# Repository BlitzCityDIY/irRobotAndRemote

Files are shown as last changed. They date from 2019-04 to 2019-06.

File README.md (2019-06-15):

This is for a rover robot built with the Adafruit Crickit board. 

It's controlled with an IR remote using an Adafruit Trinket M0, Adafruit Seesaw and custom PCB.

Coded with CircuitPython.

Project Videos:

https://youtu.be/yoQC8QCEBIY

https://youtu.be/6JI83SIRhTM

https://youtu.be/Heaa0BWK_Mk

https://youtu.be/sYn7sI7BDCw

Fusion 360 Public Links

Remote Main Body: https://a360.co/2XNJTZd

LED Cat Faceplate: https://a360.co/2WIM9Eo

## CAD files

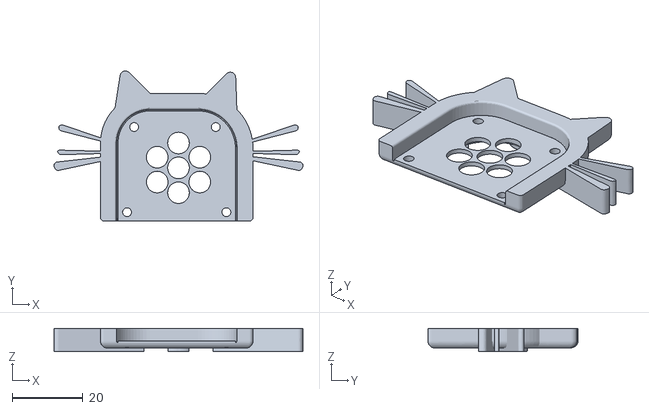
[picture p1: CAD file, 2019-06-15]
catFaceLedCover_v3.stl
70.2 x 42.3 x 6.57

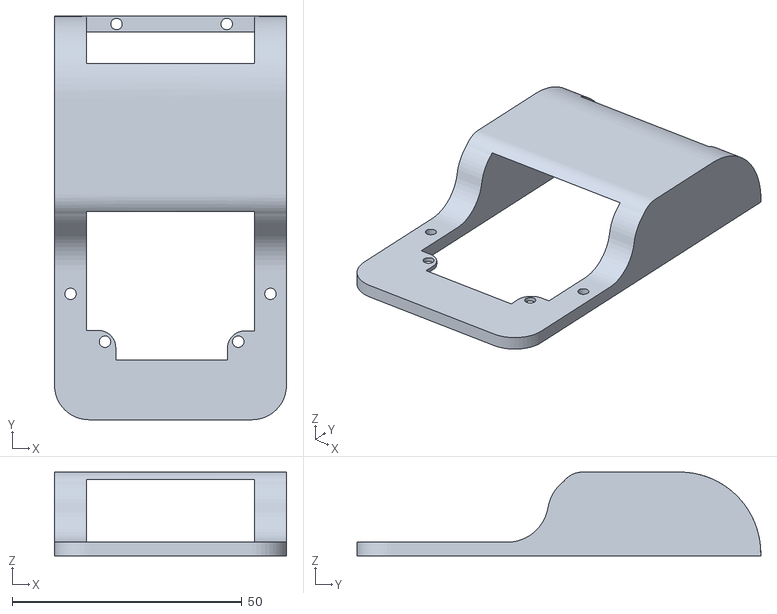
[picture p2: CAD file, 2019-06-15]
irRemoteBodyTop_v4.stl
50.5 x 87.8 x 18.3

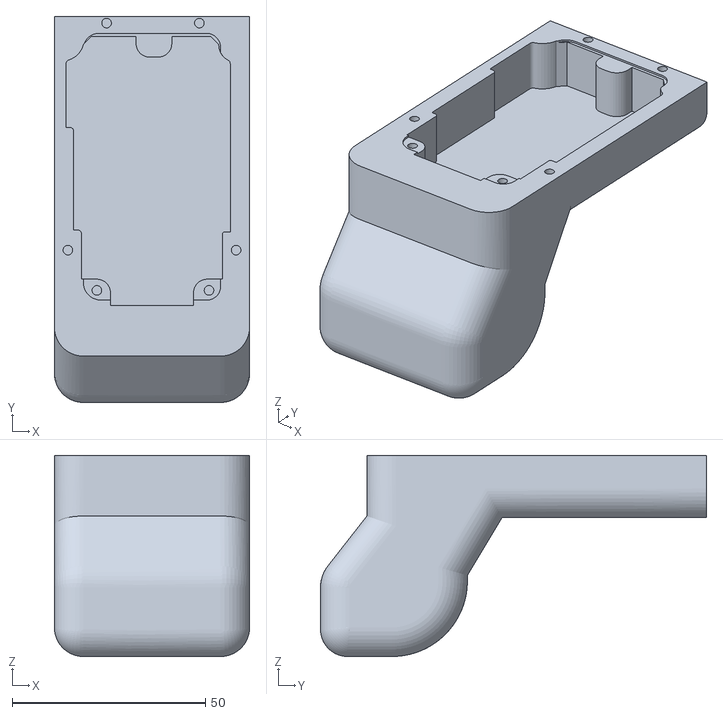
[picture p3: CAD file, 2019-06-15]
irRemoteBodyHandle_v4.stl
50.5 x 99.8 x 52.0

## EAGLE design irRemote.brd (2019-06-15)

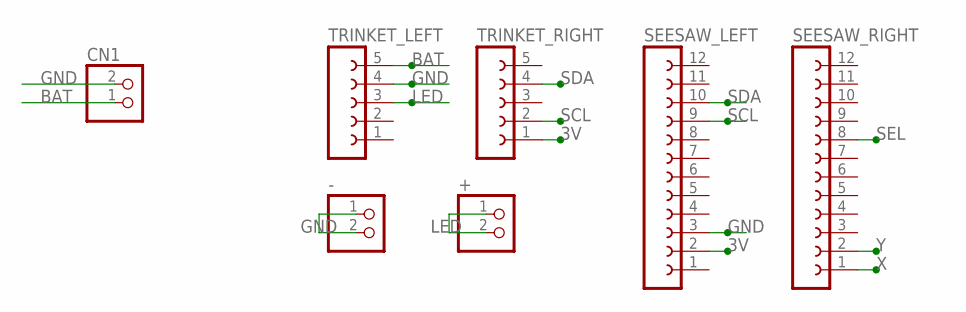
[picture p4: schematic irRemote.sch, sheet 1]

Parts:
+: PINHD-1X2; 1X02
-: PINHD-1X2; 1X02
CN1: JST_2PIN-SMT-RA; JST-PH-2-SMT-RA
SEESAW_LEFT: FE12-1; FE12
SEESAW_RIGHT: FE12-1; FE12
TRINKET_LEFT: FE05-1
TRINKET_RIGHT: FE05-1

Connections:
3V: SEESAW_LEFT.2, TRINKET_RIGHT.1; also elsewhere on the board
BAT: CN1.1 (2), TRINKET_LEFT.5
GND: -.1, -.2, CN1.2 (1), SEESAW_LEFT.3, TRINKET_LEFT.4; also elsewhere on the board
LED: +.1, +.2, TRINKET_LEFT.3
SCL: SEESAW_LEFT.9, TRINKET_RIGHT.2
SDA: SEESAW_LEFT.10, TRINKET_RIGHT.4
SEL: SEESAW_RIGHT.8; also elsewhere on the board
X: SEESAW_RIGHT.1; also elsewhere on the board
Y: SEESAW_RIGHT.2; also elsewhere on the board

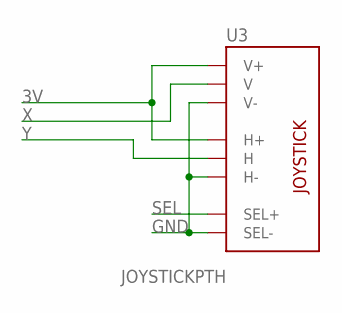
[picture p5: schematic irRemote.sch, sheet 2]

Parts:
U3: JOYSTICKPTH; JOYSTICK

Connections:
3V: U3.H1 (H+), U3.V1 (V+); also elsewhere on the board
GND: U3.B2A (SEL-), U3.H3 (H-), U3.V3 (V-); also elsewhere on the board
SEL: U3.B1A (SEL+); also elsewhere on the board
X: U3.V2 (V); also elsewhere on the board
Y: U3.H2 (H); also elsewhere on the board

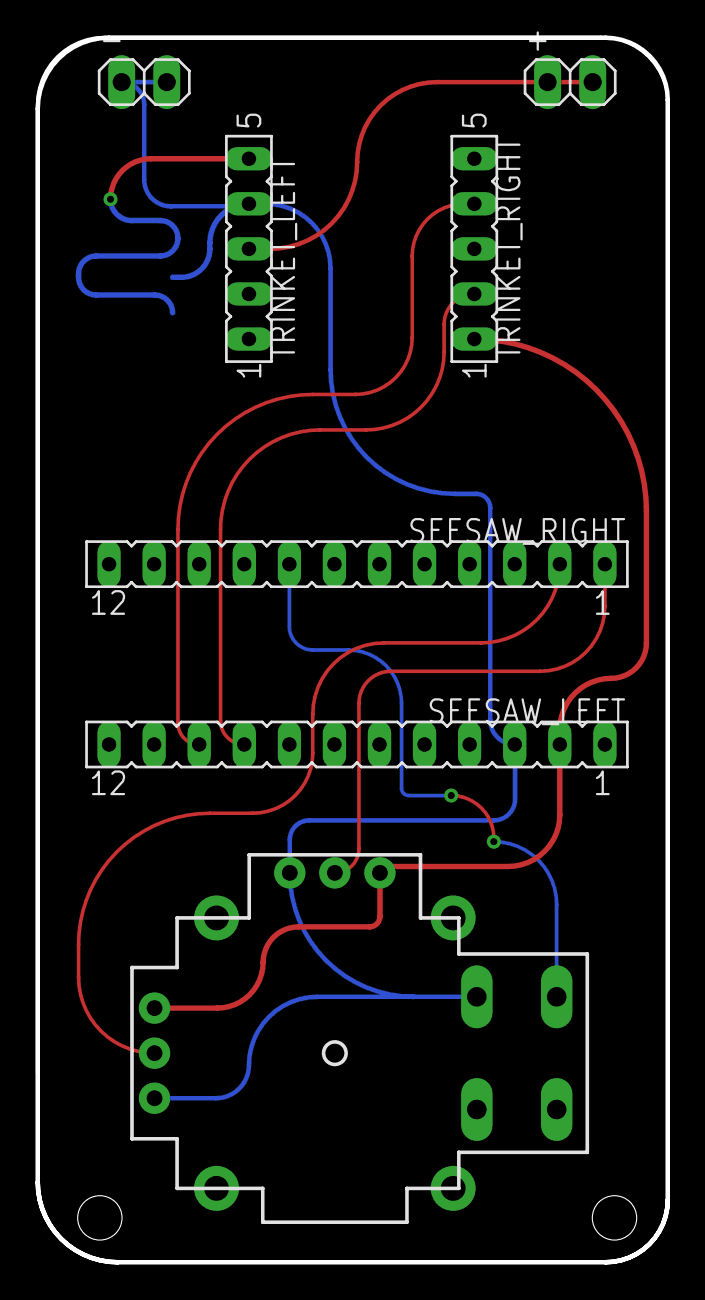
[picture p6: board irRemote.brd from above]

Board: 2 copper layers, 35.5 x 69.0 mm, 8 parts (1 on the bottom side), 9 nets.

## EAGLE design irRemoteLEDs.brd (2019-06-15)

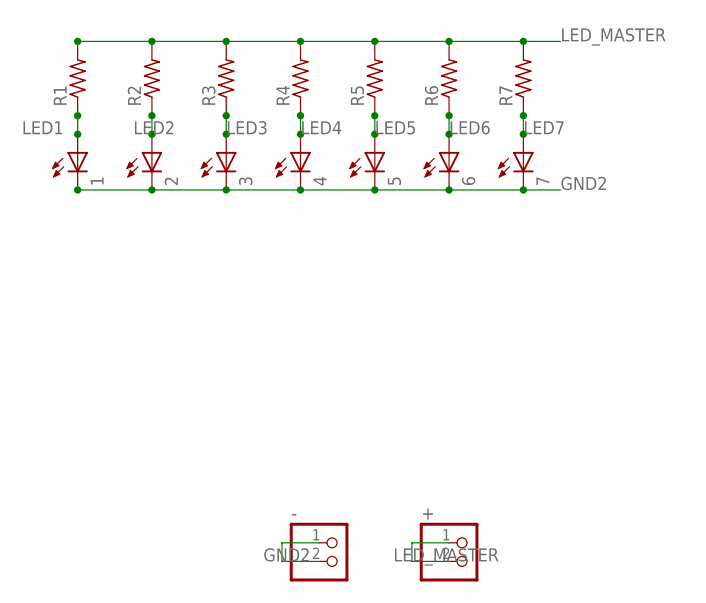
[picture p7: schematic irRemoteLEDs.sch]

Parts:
1, 2, 3, 4, 5, 6, 7: LED5MM
+: PINHD-1X2; 1X02
-: PINHD-1X2; 1X02
R1, R2, R3, R4, R5, R6, R7: R-US_M0805; M0805

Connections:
GND2: 1.K (C), 2.K (C), 3.K (C), 4.K (C), 5.K (C), 6.K (C), 7.K (C), -.1, -.2
LED1: 1.A, R1.1
LED2: 2.A, R2.1
LED3: 3.A, R3.1
LED4: 4.A, R4.1
LED5: 5.A, R5.1
LED6: 6.A, R6.1
LED7: 7.A, R7.1
LED_MASTER: +.1, +.2, R1.2, R2.2, R3.2, R4.2, R5.2, R6.2, R7.2

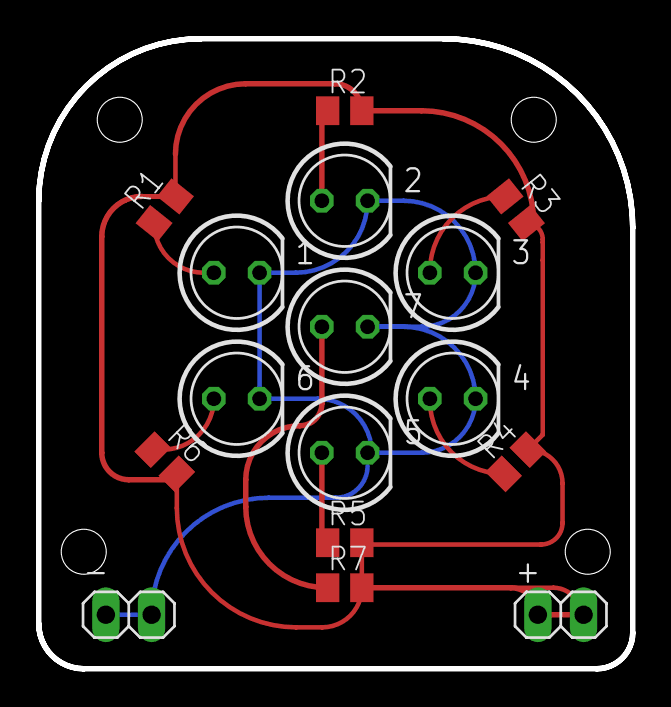
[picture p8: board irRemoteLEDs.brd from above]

Board: 2 copper layers, 33.0 x 35.0 mm, 16 parts (0 on the bottom side), 9 nets.

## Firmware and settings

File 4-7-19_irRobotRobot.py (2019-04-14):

import pulseio
import board
import adafruit_irremote
import time
from adafruit_crickit import crickit

motor_1 = crickit.dc_motor_1
motor_2 = crickit.dc_motor_2

# Create a 'pulseio' input, to listen to infrared signals on the IR receiver
pulsein = pulseio.PulseIn(board.IR_RX, maxlen=120, idle_state=True)
# Create a decoder that will take pulses and turn them into numbers
decoder = adafruit_irremote.GenericDecode()

while True:
    pulses = decoder.read_pulses(pulsein)
    try:
        # Attempt to convert received pulses into numbers
        received_code = decoder.decode_bits(pulses, debug=False)
    except adafruit_irremote.IRNECRepeatException:
        # We got an unusual short code, probably a 'repeat' signal
        # print("NEC repeat!")
        continue
    except adafruit_irremote.IRDecodeException as e:
        # Something got distorted or maybe its not an NEC-type remote?
        # print("Failed to decode: ", e.args)
        continue

    #  print("NEC Infrared code received: ", received_code)
    if received_code == [255, 2, 255, 0]:
        #  print("forward")
        motor_1.throttle = -0.5
        motor_2.throttle = -0.5 # half speed backward
        time.sleep(0.001)
    if received_code == [255, 2, 127, 128]:
        #  print("back")
        motor_1.throttle = 0.5
        motor_2.throttle = 0.5 # half speed backward
        time.sleep(0.001)
    if received_code == [255, 2, 100, 22]:
        #  print("left")
        motor_1.throttle = -0.5
        motor_2.throttle = 0.5 # half speed backward
        time.sleep(0.001)
    if received_code == [255, 2, 164, 0]:
        #  print("right")
        motor_1.throttle = 0.5
        motor_2.throttle = -0.5 # half speed backward
        time.sleep(0.001)
    if received_code == [255, 2, 191, 64]:
        #  print("stop")
        motor_1.throttle = 0
        motor_2.throttle = 0 # stop
        time.sleep(0.001)

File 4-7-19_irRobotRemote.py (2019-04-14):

import time
from board import SCL, SDA
import board
import adafruit_irremote
import pulseio
import busio
from adafruit_seesaw.seesaw import Seesaw

i2c_bus = busio.I2C(SCL, SDA)

pwm = pulseio.PWMOut(board.D4, frequency=38000, duty_cycle=2 ** 15)
pulseout = pulseio.PulseOut(pwm)
# Create an encoder that will take numbers and turn them into NEC IR pulses
encoder = adafruit_irremote.GenericTransmit(header=[9500, 4500], one=[550, 550],
                                            zero=[550, 1700], trail=0)
 
ss = Seesaw(i2c_bus)

ss.pin_mode(9, ss.INPUT_PULLUP)

last_x = 0
last_y = 0
 
while True:
    x = ss.analog_read(2)
    y = ss.analog_read(3)
    b = ss.digital_read(9)

    if not b:
            encoder.transmit(pulseout, [255, 2, 191, 64])
            time.sleep(.01)
    if (abs(x - last_x) > 3) or (abs(y - last_y) > 3):
        #  print(x, y)
        last_x = x
        last_y = y
        if x > 500 and y > 995:
            #  cpx.pixels.fill((50, 0, 0))
            encoder.transmit(pulseout, [255, 2, 255, 0])
            time.sleep(.01)
            #  forward
        if x < 10 and y > 500:
            #  cpx.pixels.fill((0, 50, 0))
            encoder.transmit(pulseout, [255, 2, 100, 22])
            time.sleep(.01)
            #  left
        if x > 995 and y > 500:
            #  cpx.pixels.fill((0, 0, 50))
            encoder.transmit(pulseout, [255, 2, 164, 0])
            time.sleep(.01)
            #  right
        if x > 500 and y < 10:
            #  cpx.pixels.fill((0, 0, 50))
            encoder.transmit(pulseout, [255, 2, 127, 128])
            time.sleep(.01)
            #  back

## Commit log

2019-04-14 IR Robot and IR Remote CircuitPython code files
2019-06-15 Eagle files for the IR remote PCBs
    Includes schematic and board files for both the main control board and the IR LED array board that plugs in via headers
    [irRemote.brd, irRemote.sch, irRemoteLEDs.brd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]
2019-06-15 3D .STL files
    [catFaceLedCover_v3.stl, irRemoteBodyHandle_v4.stl, irRemoteBodyTop_v4.stl]
